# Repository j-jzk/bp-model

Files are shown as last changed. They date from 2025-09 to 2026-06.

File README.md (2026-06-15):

# Model auta pro NXP Cup
Tento repozitář obsahuje CAD modely vytvořené pro mou bakalářskou práci „Sestavení modelu auta pro NXP Cup a jeho programové řízení“.

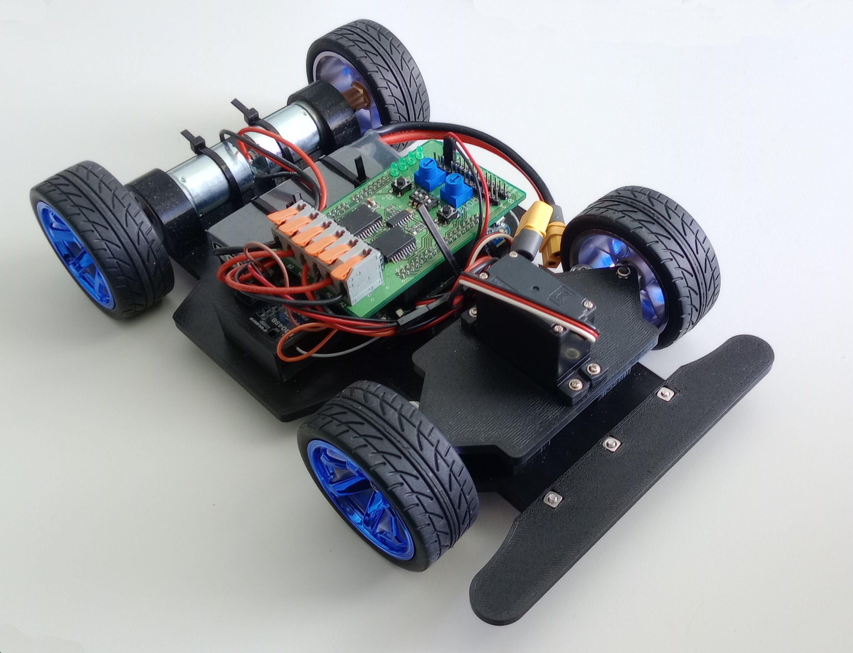
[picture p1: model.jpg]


Odkazy:
 - [návod na sestavení](https://github.com/j-jzk/bp-prace/blob/master/navod.md)
 - [text práce](https://github.com/j-jzk/bp-prace/blob/master/2026_JEZ0098_BP.pdf)
 - [kód pro mikrokontrolér](https://github.com/j-jzk/bp-program)

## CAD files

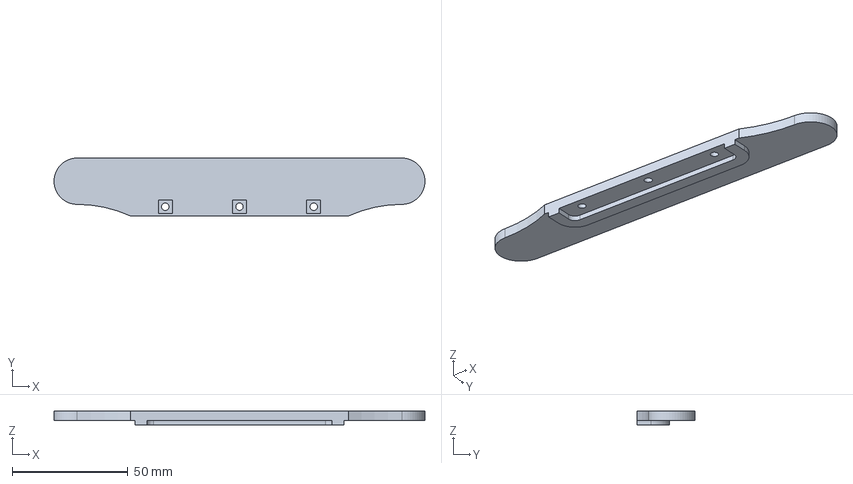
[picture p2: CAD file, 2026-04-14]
bumper.FCStd
160.0 x 25.0 x 6.00 mm

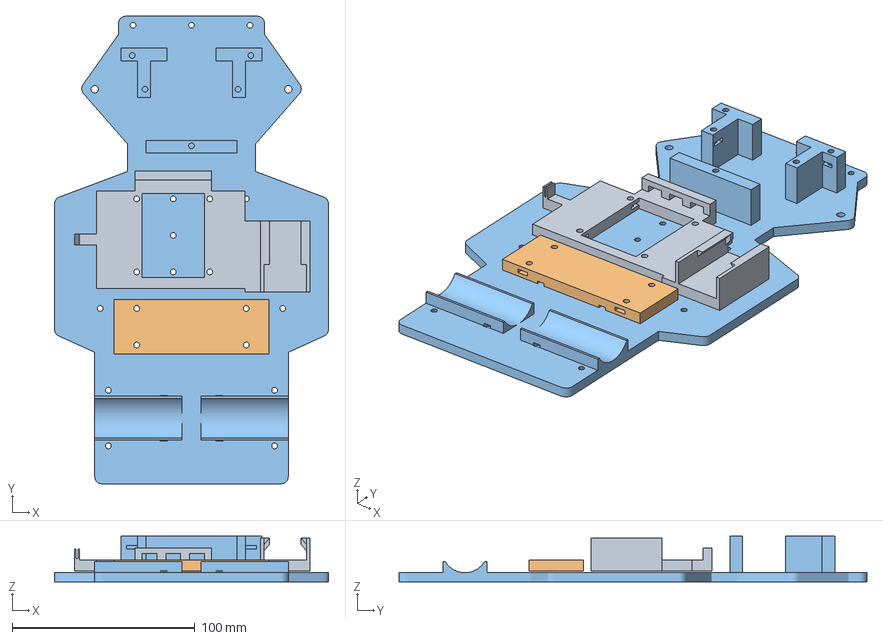
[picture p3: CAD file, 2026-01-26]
accessory_holders.FCStd
150.0 x 256.0 x 25.0 mm
držák pro MCU + RC RX
držák pro baterii
bottom_plate

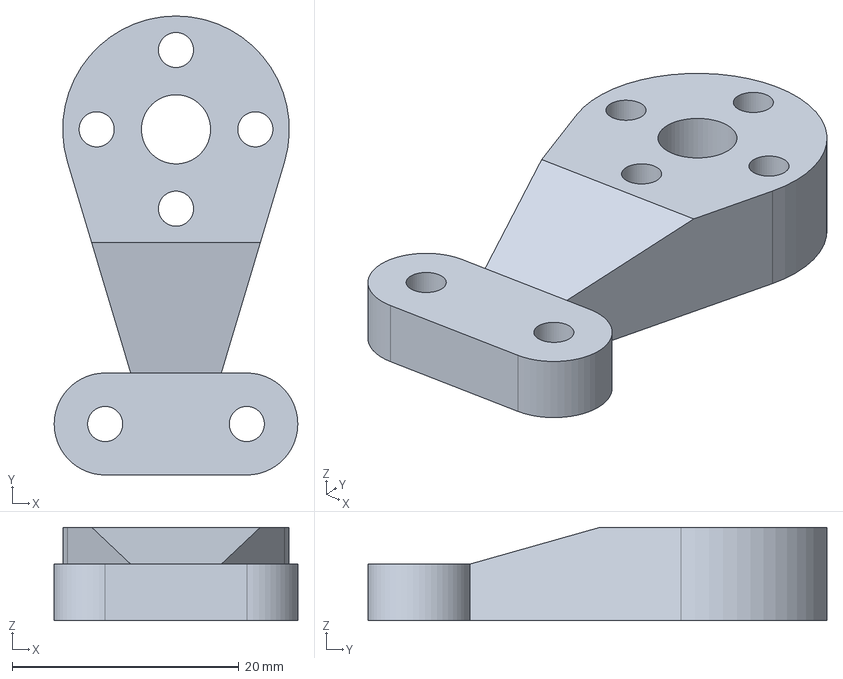
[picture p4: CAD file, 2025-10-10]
servo_arm.FCStd
21.5 x 40.5 x 8.25 mm

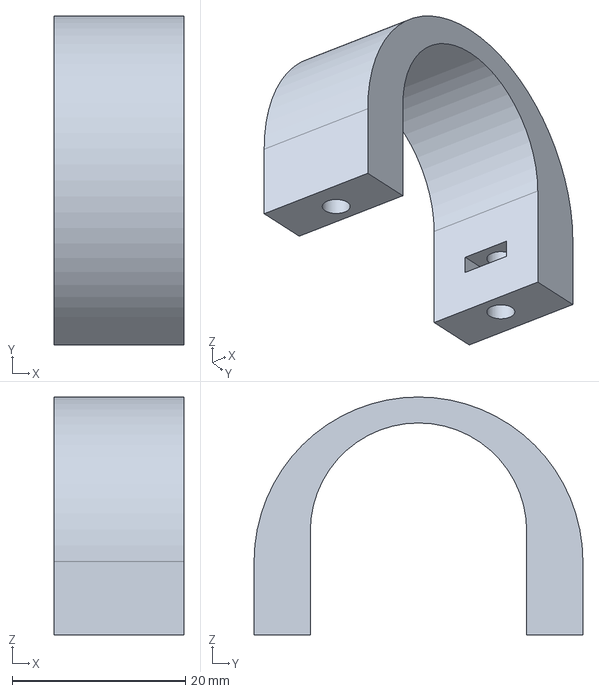
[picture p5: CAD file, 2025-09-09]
motor_bracket.FCStd
15.0 x 38.0 x 27.5 mm

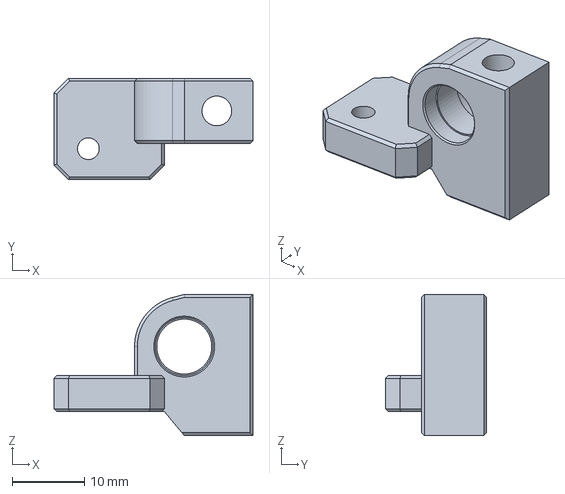
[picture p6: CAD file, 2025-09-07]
wheel_spindle.FCStd
27.5 x 14.0 x 19.5 mm

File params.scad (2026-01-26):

// circle and arc resolution
$fa = $preview ? 12 : 5;
$fs = $preview ? 2 : 0.7;

e = 0.01;  // epsilon
m3_d = 3.2;  // hole diameter for an M3 screw
corner_r = 4; // corner radius

plate_thickness = 5;
// positions of the wheel/motor mountings (not the wheels themselves)
back_wheel_pos = [53, 0];
front_wheel_pos = [53, 180];

// Widths on the plate are measured from the main axis => they are halved!

// the back plate on which the motors and back wheels are mounted;
// needs to be long enough for the wheels to fit
back_plate_length = 36*2;
// width of the cutout behind and in front of the front wheels for them to
// steer freely
steering_cutout_width = 35;
// Y axis length of the triangle on which the front wheels are mounted (in
// either direction => the actual length is 2*wheel_mount_length)
wheel_mount_length = 20;
// the plate on which the battery is mounted
middle_plate_width = 75;
// the Y coordinate of the outer corner
middle_plate_maxy = front_wheel_pos.y - wheel_mount_length - 25 - 15;

motor_d = 25;
motor_len = 47.8;
motor_bracket_len = 15;
motor_bracket_screw_hole_margin = 2.75;
motor_cable_tie_thickness = 1 + 0.5; // with tolerance
motor_cable_tie_width = 3.5 + 0.5; // with tolerance

accessory_hole_spacing = 20;

servo_plate_support_height = 20;
// hole positions for attaching the servo plate to the bottom plate;
// when edited, you should probably adjust the hard-coded parameters of the supports in servo_plate.scad.
// origin is assumed to be on the front wheel axis
servo_plate_hole_poss = [
    // T-shaped support, left side
    [-13.5 - 10 + 6, 15.5 + 4 + e],
    [-13.5 - (25-7)/2 - 4 - e, 0],
    // T-shaped support, right side
    [13.5 + 10 - 6, 15.5 + 4 + e],
    [13.5 + (25-7)/2 + 4 + e, 0],
    // horizontal support
    // [0, -28-3+e]
];

bumper_socket_width = 40;
bumper_socket_length = 24 + 1; // min 9 + tolerance
bumper_hole_margin = 5;
bumper_hole_x = 32; // X coordinate of the left and right hole
bumper_hole_d = m3_d;

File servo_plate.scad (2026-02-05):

use <utils.scad>
include <params.scad>

/*
 * The origin is on the front wheel axis.
 */

module base_shape_2d() {
    offset(r = corner_r) offset(r = -corner_r) // rounded corners
        mirror_copy()
            polygon([
                [0-e, -30],
                [steering_cutout_width, -30],
                [steering_cutout_width, -wheel_mount_length],

                [front_wheel_pos.x+m3_d+5, 0],

                [bumper_socket_width, wheel_mount_length],
                [bumper_socket_width, 30],
                [0-e, 30],
            ]);
}

module servo_mount() {
    // origin is the rotor's axis
    // dimensions accoding to https://futaba.uk/products/fut05102732-3

    // servo hole
    translate([-10 - 1.0/2, -29.9 - 1.0/2, 0]) // translate the rotor axis to [0,0]
        cube([20 + 1, 40 + 1, plate_thickness + 2*e]);

    // screw holes
    module _screw_hole() {
        cylinder(d=2.1, h=plate_thickness + 2*e);
    }

    mirror_copy() {
        translate([-5, 14.85]) _screw_hole();
        translate([-5, -34.65]) _screw_hole();
    }
}

module kingpin_holes() {
    screw_d = 4 + 0.1;  // 4 mm + tolerance
    pocket_height = 2;

    module _kingpin_hole() {
        translate([0,0,-e]) cylinder(d=screw_d, h=plate_thickness + 2*e);
        translate([0,0, plate_thickness - pocket_height + e])
            linear_extrude(height = pocket_height)
                m3_nut_hexagon();
    }

    mirror_copy()
        translate([front_wheel_pos.x, 0]) _kingpin_hole();
}

module supports() {
    // width/thickness of the rectangles; must be enough to accomodate holes for the nuts
    w = 7;

    module _2d() {
        // T-shaped part
        mirror_copy()
            translate([13.5, 15.5])
                polygon([
                    // horizontal part
                    [0, 0], [0, w], [20, w], [20, 0],
                    // vertical part
                    [(25-w)/2, 0], [(25-w)/2, -20], [(25+w)/2, -20], [(25+w)/2, 0],
                ]);

        // horizontal rectangle
        // translate([0, -28 - w/2]) square([50, w], center=true);
    }

    mirror([0,0,1])
        difference() {
            linear_extrude(height = servo_plate_support_height) _2d(); 

            // nut holes
            translate([0, 0, servo_plate_support_height]) {
                for (pos = servo_plate_hole_poss) {
                    translate(pos) m3_square_nut_hole();
                }
            }
        }
}

difference() {
    union() {
        linear_extrude(height = plate_thickness) base_shape_2d();
        supports();
    }

    // y=10.2894 is a value calculated in FreeCAD
    translate([0, 10.2894, 0-e]) servo_mount();
    kingpin_holes();
}

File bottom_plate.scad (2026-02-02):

use <utils.scad>
include <params.scad>

/*
 * The origin of the vehicle is in the middle of the back wheel axis and the
 * front of the vehicle is in the +Y direction from it.
 */

module base_plate_2d() {
    module _right_half() {
        // from the bottom up
        polygon([
            [0-e, -back_plate_length/2],
            [back_wheel_pos.x, -back_plate_length/2],
            [back_wheel_pos.x, back_plate_length/2],

            // middle plate for the accessories
            [middle_plate_width, back_plate_length/2 + 10],
            [middle_plate_width, middle_plate_maxy],

            // cut-out for the front wheels to steer
            [steering_cutout_width, middle_plate_maxy+15],
            [steering_cutout_width, front_wheel_pos.y-wheel_mount_length],
            // front wheel mounting point
            [front_wheel_pos.x+m3_d+5, front_wheel_pos.y],

            [bumper_socket_width, front_wheel_pos.y + wheel_mount_length],
            [bumper_socket_width, front_wheel_pos.y + wheel_mount_length + bumper_socket_length],
            [0-e, front_wheel_pos.y + wheel_mount_length + bumper_socket_length],
        ]);
    }

    // rounded corners
    offset(r = corner_r) offset(r = -corner_r) {
        mirror_copy() _right_half();
    }
}

module _hole(pos) {
    translate([pos.x, pos.y, 0-e]) conic_hole_m3(plate_thickness + 2*e);
}

module accessory_holes() {
    module _grid() {
        hole_count = [
            ceil(middle_plate_width * 2 / accessory_hole_spacing),
            ceil(front_wheel_pos.y / accessory_hole_spacing)
        ];
        min_x = floor(-middle_plate_width / accessory_hole_spacing) * accessory_hole_spacing - accessory_hole_spacing/2;
        // position min_y such that the middle of the y axis is in between two rows of holes
        min_y = (front_wheel_pos.y / 2) % accessory_hole_spacing - accessory_hole_spacing/2;

        for (
            x = [min_x : accessory_hole_spacing : middle_plate_width],
            y = [min_y : accessory_hole_spacing : front_wheel_pos.y]
        ) {
            _hole([x, y]);
        }
    }

    intersection() {
        _grid();
        // the polygon where we want the holes
        translate([0,0,-e]) mirror_copy() linear_extrude(plate_thickness + 2*e)
            polygon([
                // from the bottom right
                [0-e, back_plate_length/2 - 10],
                [back_wheel_pos.x - 10, back_plate_length/2 - 10],
                [back_wheel_pos.x - 10, back_plate_length/2 + 10],

                [middle_plate_width - 10, back_plate_length/2 + 10],
                [middle_plate_width - 10, middle_plate_maxy],

                [steering_cutout_width, front_wheel_pos.y-70],
                [steering_cutout_width, front_wheel_pos.y-30-15],
                [0-e, front_wheel_pos.y-30-15]
                // [0-e, front_wheel_pos.y-30],
            ]);
    }
}

module kingpin_holes() {
    pocket_height = 2;
    screw_head_d = 7;
    screw_d = 4 + 0.1;  // diameter 4 mm + tolerance

    module _kingpin_hole() {
        cylinder(h = plate_thickness + e, d = screw_d);
        translate([0, 0, 0-e]) cylinder(h = pocket_height+e, d = screw_head_d + 0.3);
    }

    mirror_copy()
        translate([front_wheel_pos.x, front_wheel_pos.y, 0])
            _kingpin_hole();
}

module motor_holder() {
    // the side should be cca 0.8-1.2 mm wide for printing
    translate([-motor_len, 0, 0])
        difference() {
            translate([0, -(motor_d-1)/2, 0]) cube([motor_len, motor_d-1, motor_d*0.25]);
            translate([0-e, 0, motor_d/2]) rotate([0, 90, 0]) cylinder(r = motor_d/2, h=motor_len+2*e);
        }
}
module motor_holder_holes() {
    // screw holes for the bracket
    mirror_copy([0,1,0])
        _hole([
            -motor_bracket_len/2,
            motor_d/2 + motor_bracket_screw_hole_margin,
        ]);

    // girder for the cable tie
    // variant 1: the hole peeks through the bottom
    // translate([-motor_len + 10, 0, motor_d/2 ])
    //     rotate(90, [0,1,0])
    //         difference() {
    //             cylinder(h = motor_cable_tie_width, r = motor_d/2 + motor_cable_tie_thickness, center=true);
    //             cylinder(h = motor_cable_tie_width, r = motor_d/2, center=true);
    //         }
    
    // variant 2: the hole is fully hidden, larger D
    translate([-motor_len + 10, 0, motor_d/2 + 13])
        rotate(90, [0,1,0])
            difference() {
                cylinder(h = motor_cable_tie_width, r = motor_d/2 + 10 + motor_cable_tie_thickness, center=true);
                cylinder(h = motor_cable_tie_width, r = motor_d/2 + 10, center=true);
            }
}

module servo_plate_screw_holes() {
    translate([0, front_wheel_pos.y])
        for (pos = servo_plate_hole_poss) {
            _hole(pos);
        }
}

module bumper_holes() {
    translate([0, front_wheel_pos.y + wheel_mount_length + bumper_socket_length - bumper_hole_margin, 0])
        union() {
            _hole([-bumper_hole_x, 0]);
            _hole([0, 0]);
            _hole([bumper_hole_x, 0]);
        }
}

difference() {
    union() {
        // base plate
        linear_extrude(height = plate_thickness) base_plate_2d();
        // motor holders
        mirror_copy()
            translate([back_wheel_pos.x, back_wheel_pos.y, plate_thickness])
                motor_holder();
    }

    // holes
    mirror_copy()
        translate(back_wheel_pos) motor_holder_holes();
    kingpin_holes();
    accessory_holes();
    bumper_holes();
    servo_plate_screw_holes();
}

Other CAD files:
geometry.FCStd
utils.scad

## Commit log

2025-08-14 initial commit - base plate with motor holders
    [bottom_plate.scad, motor_bracket.scad, params.scad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]
2025-09-02 add the wheel spindle
    [wheel_spindle.FCStd]
2025-09-07 zaokrouhli rozměry; oprav náboj kola, aby se do něj vlezl kulový čep
    [params.scad, wheel_spindle.FCStd]
2025-09-09 redesign - držáky motorů, díra pro kingpin, díry pro elektroniku
    [bottom_plate.scad, motor_bracket.FCStd, motor_bracket.scad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]
2025-10-05 přidej podpory pro servo panel
    [bottom_plate.scad, params.scad, utils.scad]
2025-10-05 přidej servo panel
    [bottom_plate.scad, params.scad, servo_plate.scad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]
2025-10-05 přidej rameno pro servo
    [servo_arm.FCStd]
2025-10-05 uprav síť děr pro elektroniku
    Uprav síť děr pro elektroniku, aby střed vozidla byl mezi čtyřmi dírami.
    (Aby střed, který je nejvíce namáhaný, byl pevnější.)
    [bottom_plate.scad]
2025-10-05 uprav držáky pro motory
    - prodluž je na celou délku motoru
    - přidej průvlaky pro upevnění zadní části motoru stahovací páskou
    [bottom_plate.scad, params.scad]
2025-10-06 přidej místo pro nárazník
    [bottom_plate.scad, params.scad]
2025-10-07 nastav vyšší rozlišení křivek při renderu
    [params.scad, servo_plate.scad]
2025-10-07 sniž držáky pro motor
    [bottom_plate.scad]
2025-10-08 uprav rameno serva
    - odstraň zapuštění šroubů
    - přidej díru pro zpřístupnění šroubu, kterým bude upevněna příruba na
    servo
    [servo_arm.FCStd]
2025-10-10 uprav upevnění serva
    - zvyš rameno o 1.25 mm, aby se vyrovnal rozdíl ve výšce, když se servo
    upevní s gumovými nožičkami
    - zmenši díru na M2
    [servo_arm.FCStd, servo_plate.scad]
2025-10-20 přidej soubor s geometrií
    [geometry.FCStd]
2026-01-21 přidej držáky pro elektroniku
    [accessory_holders.FCStd]
2026-01-26 oprav nedostatky v držácích pro elektroniku
    - příkop pro stahovací pásky udělej dole otevřený
    - užší rozvor a tenčí stěny držáku na anténu, také ji posuň pryč od MCU
    - vazák na kabely posunutý trochu dál
    - držák na RC přijímač posuň, aby se neohýbaly konektory
    [accessory_holders.FCStd]
2026-01-26 udělej ostřejší výřez pro zatáčení
    [bottom_plate.scad, params.scad, servo_plate.scad]
2026-01-26 podpory pro servo desku přesuň přímo na ni
    [bottom_plate.scad, params.scad, servo_plate.scad]
2026-02-02 přidej u některých rozměrů větší toleranci
    [bottom_plate.scad, servo_plate.scad, utils.scad]
2026-02-05 uprav servo panel, aby seděl se spodní deskou
    [geometry.FCStd, servo_plate.scad]
2026-02-16 oprav znovu zapuštění šroubů
    [utils.scad]
2026-04-14 přidej nárazník
    [bumper.FCStd]
